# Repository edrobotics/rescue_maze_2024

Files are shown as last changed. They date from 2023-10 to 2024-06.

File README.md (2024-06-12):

# Rescue Maze 2024

Repository for ED Robotics' participation in the Robocup Junior Rescue Maze 2024 competition.

The contents of this repository were used in RoboCup Junior SM (Swedish Championships) 2024.

The code and CAD models are provided as-is, without any additional work done after the competition. The code (and hardware) did not work as expected, so keep that in mind.

## Performance

- RoboCupJunior Sweden 2024: Last place, 5 points :(

## Conclusions

Minimum Viable Product is a good idea that probably should have been prioritised more.

## Note:

This was our second year doing robotics. The code may contain trace amounts of spaghetti.

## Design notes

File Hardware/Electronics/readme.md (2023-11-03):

# Electronics
In this folder, all electronics-related things are stored. This is mostly schematics and PCBs.

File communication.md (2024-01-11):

# Communication standards for EDR RCJ2024
## Teensy to Pi
Communication method: I2C

Information from teensy to Pi:
- Motor data
  - Speed
  - Position - Position since last call to startDistanceMeasure
- ToF data
- IMU Data
- Colour sensor data
- Battery voltage

Information from Pi to teensy:
- Motor control values
  - Wanted speed
  - Acceleration limits?

### Concrete implementation
The two computers are synchronized. Communication (and some more things) happen like this:

<!-- Websequencediagrams code for the following image (could also use js-sequence-diagrams)
title Communication: Teensy-Pi
Pi->Teensy: Write control data
note right of Teensy: While waiting, run motor control loop
Pi->Teensy: Write control data end
note right of Teensy: Use the control data
Pi->Teensy: Check if data is ready
Teensy->Pi: Respond if ready or not (if it has\nbeen updated since last read)
Pi->Teensy: I want to read data
Teensy->Pi: Data
note right of Teensy: While sending data, read all other sensors\n(and perform misc. tasks)
Pi->Teensy: I have read all that I want
note right of Teensy: Set data ready flag to 0
note right of Teensy: Continue reading sensors if needed
note right of Teensy: Update the data read variable (byte array)
note right of Teensy: Set data ready flag to 1
note right of Teensy: Wait for new control data write (go back to top) -->

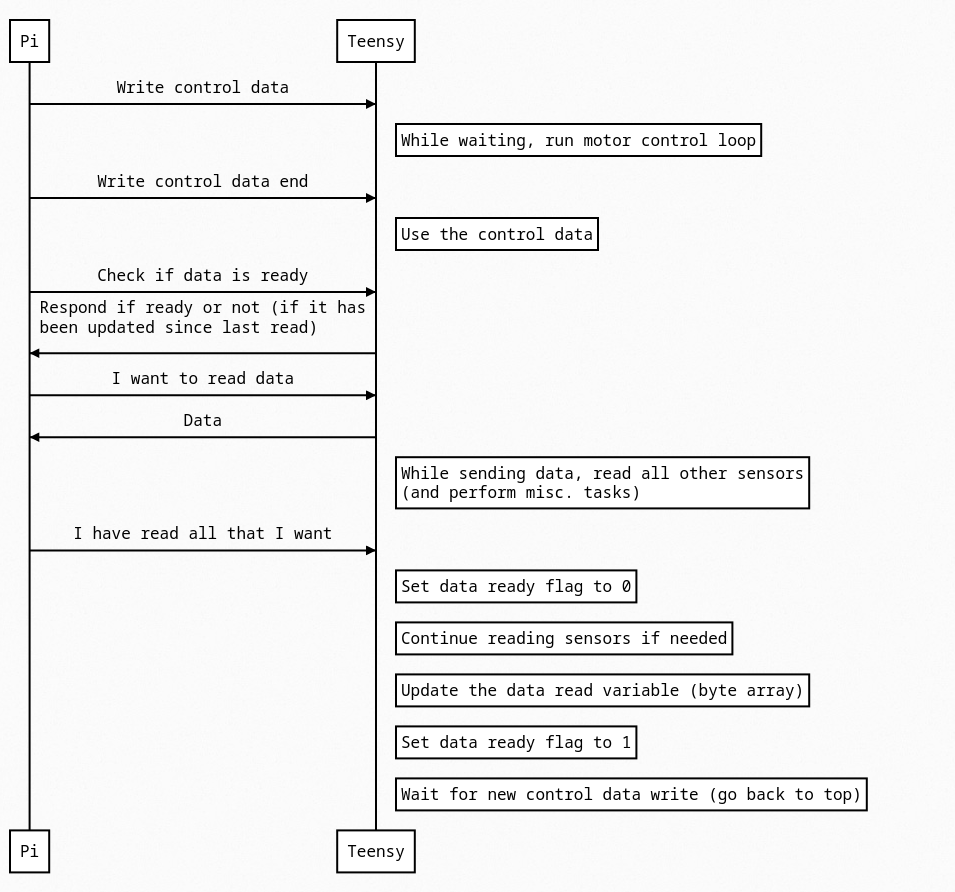
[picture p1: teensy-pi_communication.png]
Communication diagram


## Vision to Navigation
Communication method: Socket communication

Port: 4242  
Bidirectional: Yes (?)

Information that the protocol should be able to transmit:

- Victim type (including none)
    - Also includes potential victims
- Victim position
- Timestamp for captured image frame

If victim is direclty right/left, first send potential victim, with position and timestamp. Then navigation slows down or stops and updates the slowing/stopping status to the vision program. Then a normal victim type may be sent, the side, position and timestamp.

If victim is in front or out to the sides (for example in adjacent tile), send an unconfirmed victim type, side, position(?) (different from potition above) and timestamp. Then it is up to global navigation to decide wether to investigate or not. Then normal victim handling takes over. No confirmations are sent.

### Concrete implementation
Start char: '!'  
Delimiter: ','

Message types:
- Victim detection: 'v'
- Confirmation: 'c'

Victim detection message structure: !v,\<detection type>,\<victim type>,\<camera>,\<position>,\<timestamp>

- Detection type: 'p'/'c'
- Victim type: 'g'/'y'/'r'/'u'/'s'/'h'
- Camera: Integer staring from 0, incrementing by 1. Fusion program determines left/right
- Position:
    - \<x-coord>,\<y-coord>
    - Integer in mm from the camera center of FOV. Positive direction is normal math coordinate system (positive right-up)
- Timestamp: Unix millisecond timestamp

Confirmation message structure: !c

## Navigation threads
Communication method: Shared variables

Data that should be shared:
- Local robot pose
- Global robot pose
- Array/vector/queue of commands for local to execute
- Fusion -> (global) -> local: detection slowdown
- Fusion -> global -> local: kit drop interrupt
    - Read what to drop and where from other variable
- speed setting (slow, normal, turbo)
- Ground colour data from fusion
- Ramp data: direction, x-length, y-length, (length)
- Väggar
- Obstacles?
- Bump sensor

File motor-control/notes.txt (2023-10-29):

PID Library: https://github.com/br3ttb/Arduino-PID-Library
Motor PID Library: https://github.com/natnqweb/Motor_PID

Need to make it clear how it is done whether both edges are counted or just one, with CPR.

Need to check all types, especially float/double with the PID Library

Left to do:
Migrate to teensy?
Tune constants
Handle integral windup
Incorporate PWM "bump"?
Finish calibration routine:
    Make linear regression on the Arduino
    Store the regression function in EEPROM(or other)
Communication with raspberry

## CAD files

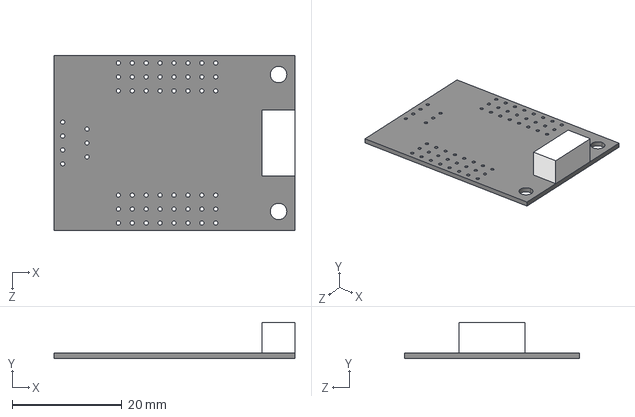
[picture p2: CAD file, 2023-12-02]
Hardware/CAD/Parts_library/dfrobot_io_expander.step
44.0 x 6.65 x 32.0 mm

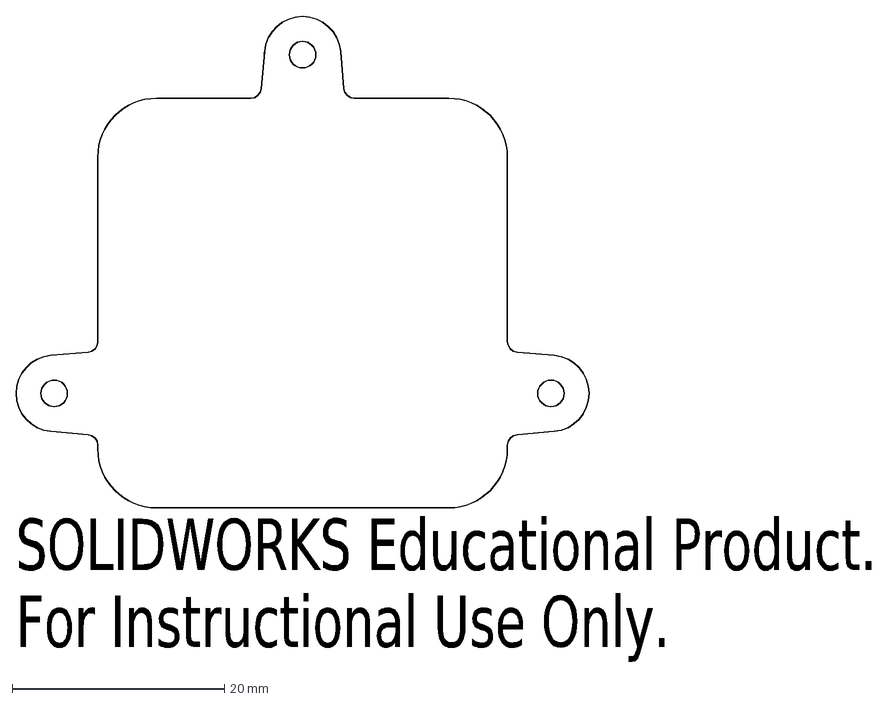
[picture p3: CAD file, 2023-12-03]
Hardware/Electronics/kicad_RCJ/3d-models/lidar_testing.DXF
SOLIDWORKS Educational Product.
For Instructional Use Only.

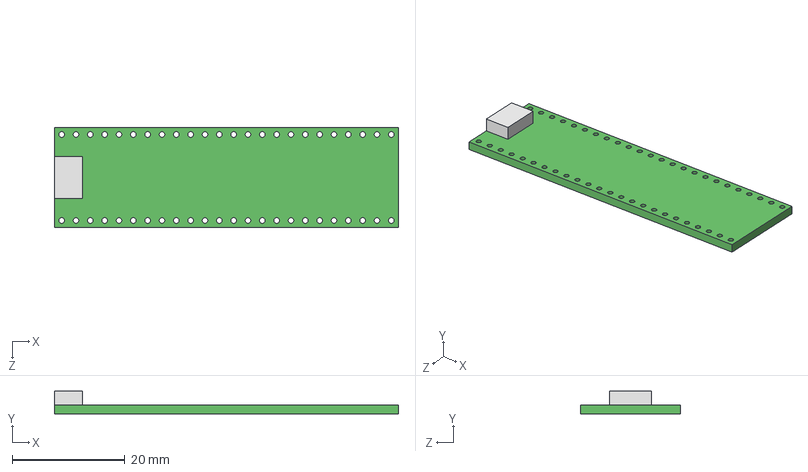
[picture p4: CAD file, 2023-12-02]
Hardware/CAD/Parts_library/teensy_4.1.step
61.0 x 4.07 x 17.8 mm

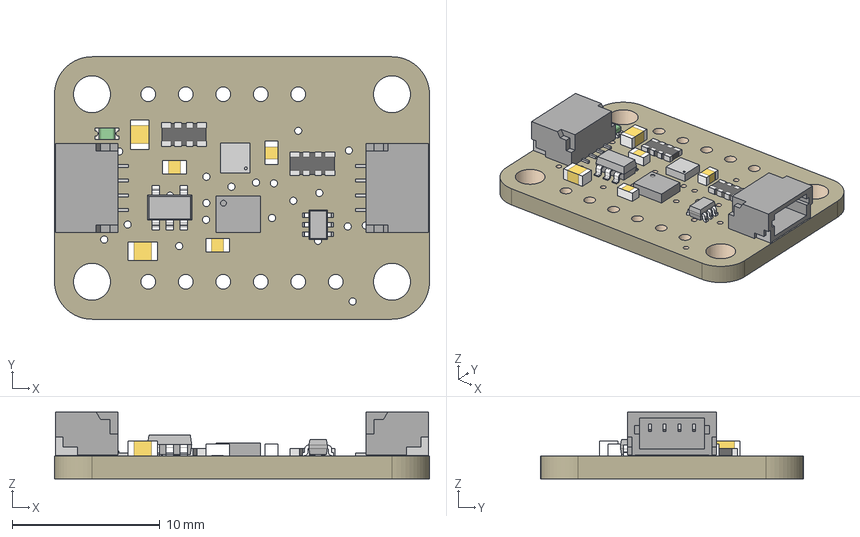
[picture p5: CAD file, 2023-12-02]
Hardware/Electronics/kicad_RCJ/3d-models/4517_LSM6DSOX-LIS3MDL.step
25.4 x 17.8 x 4.53 mm
Board
10uF x 2
AP2112K-3.3
1uF x 3
10K x 2
BSS138
STEMMA_I2C_QT x 2
GREEN
LIS3MDL
LSM6DSOX

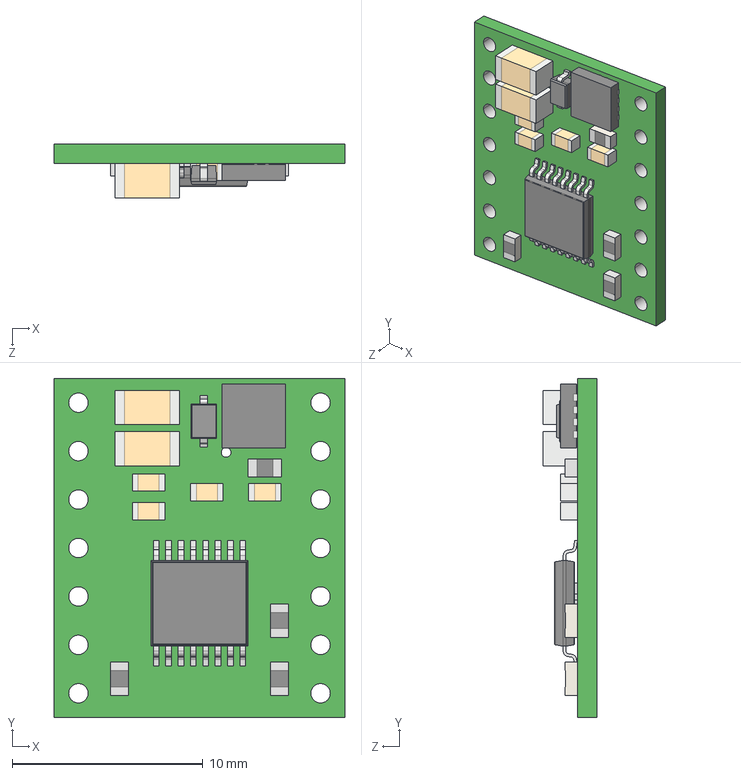
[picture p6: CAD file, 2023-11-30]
Hardware/Electronics/kicad_RCJ/3d-models/drv887x-single-brushed-dc-motor-driver-carrier.step
15.2 x 17.8 x 2.82 mm

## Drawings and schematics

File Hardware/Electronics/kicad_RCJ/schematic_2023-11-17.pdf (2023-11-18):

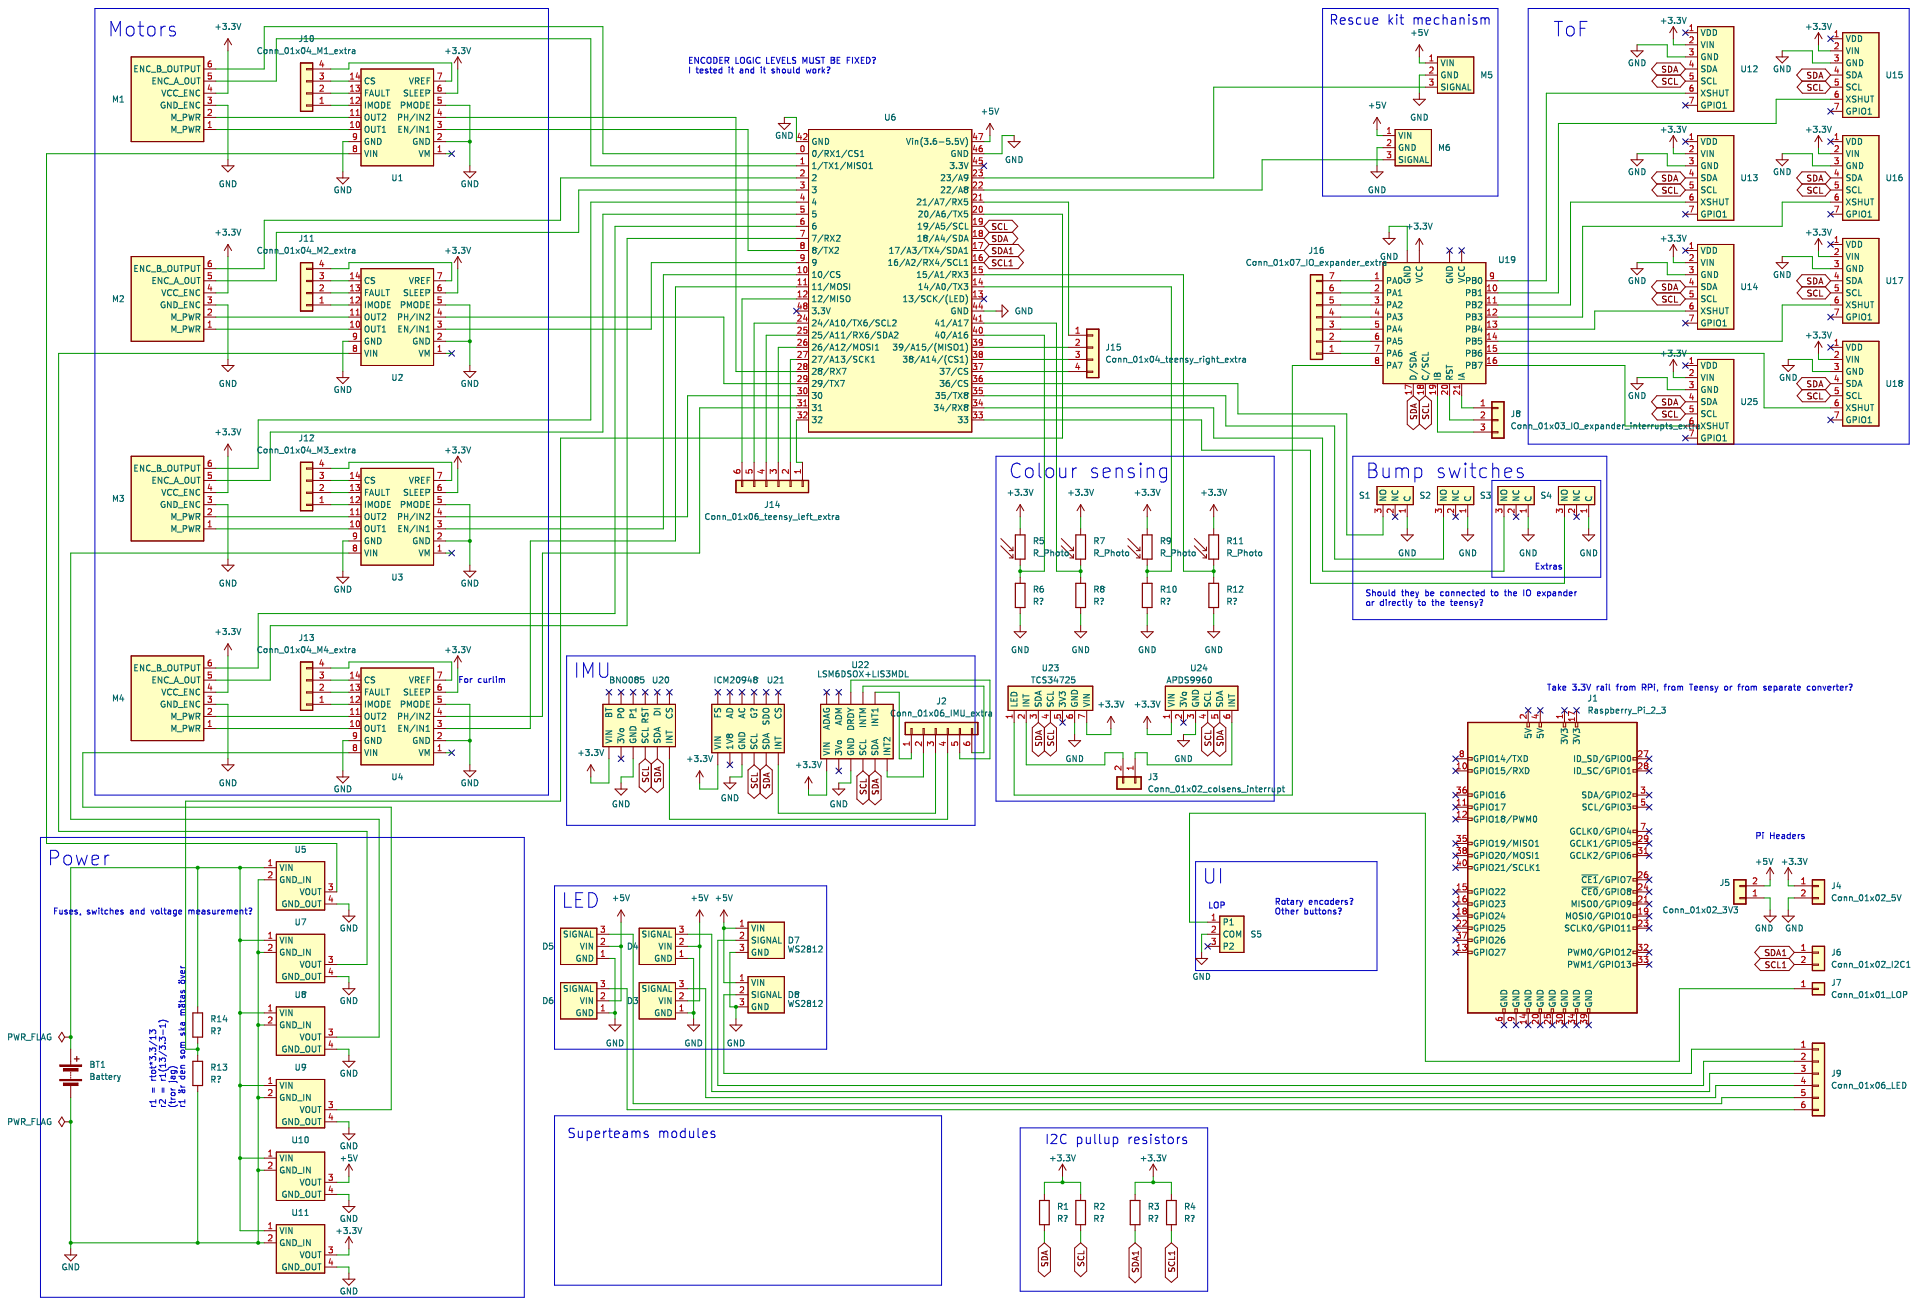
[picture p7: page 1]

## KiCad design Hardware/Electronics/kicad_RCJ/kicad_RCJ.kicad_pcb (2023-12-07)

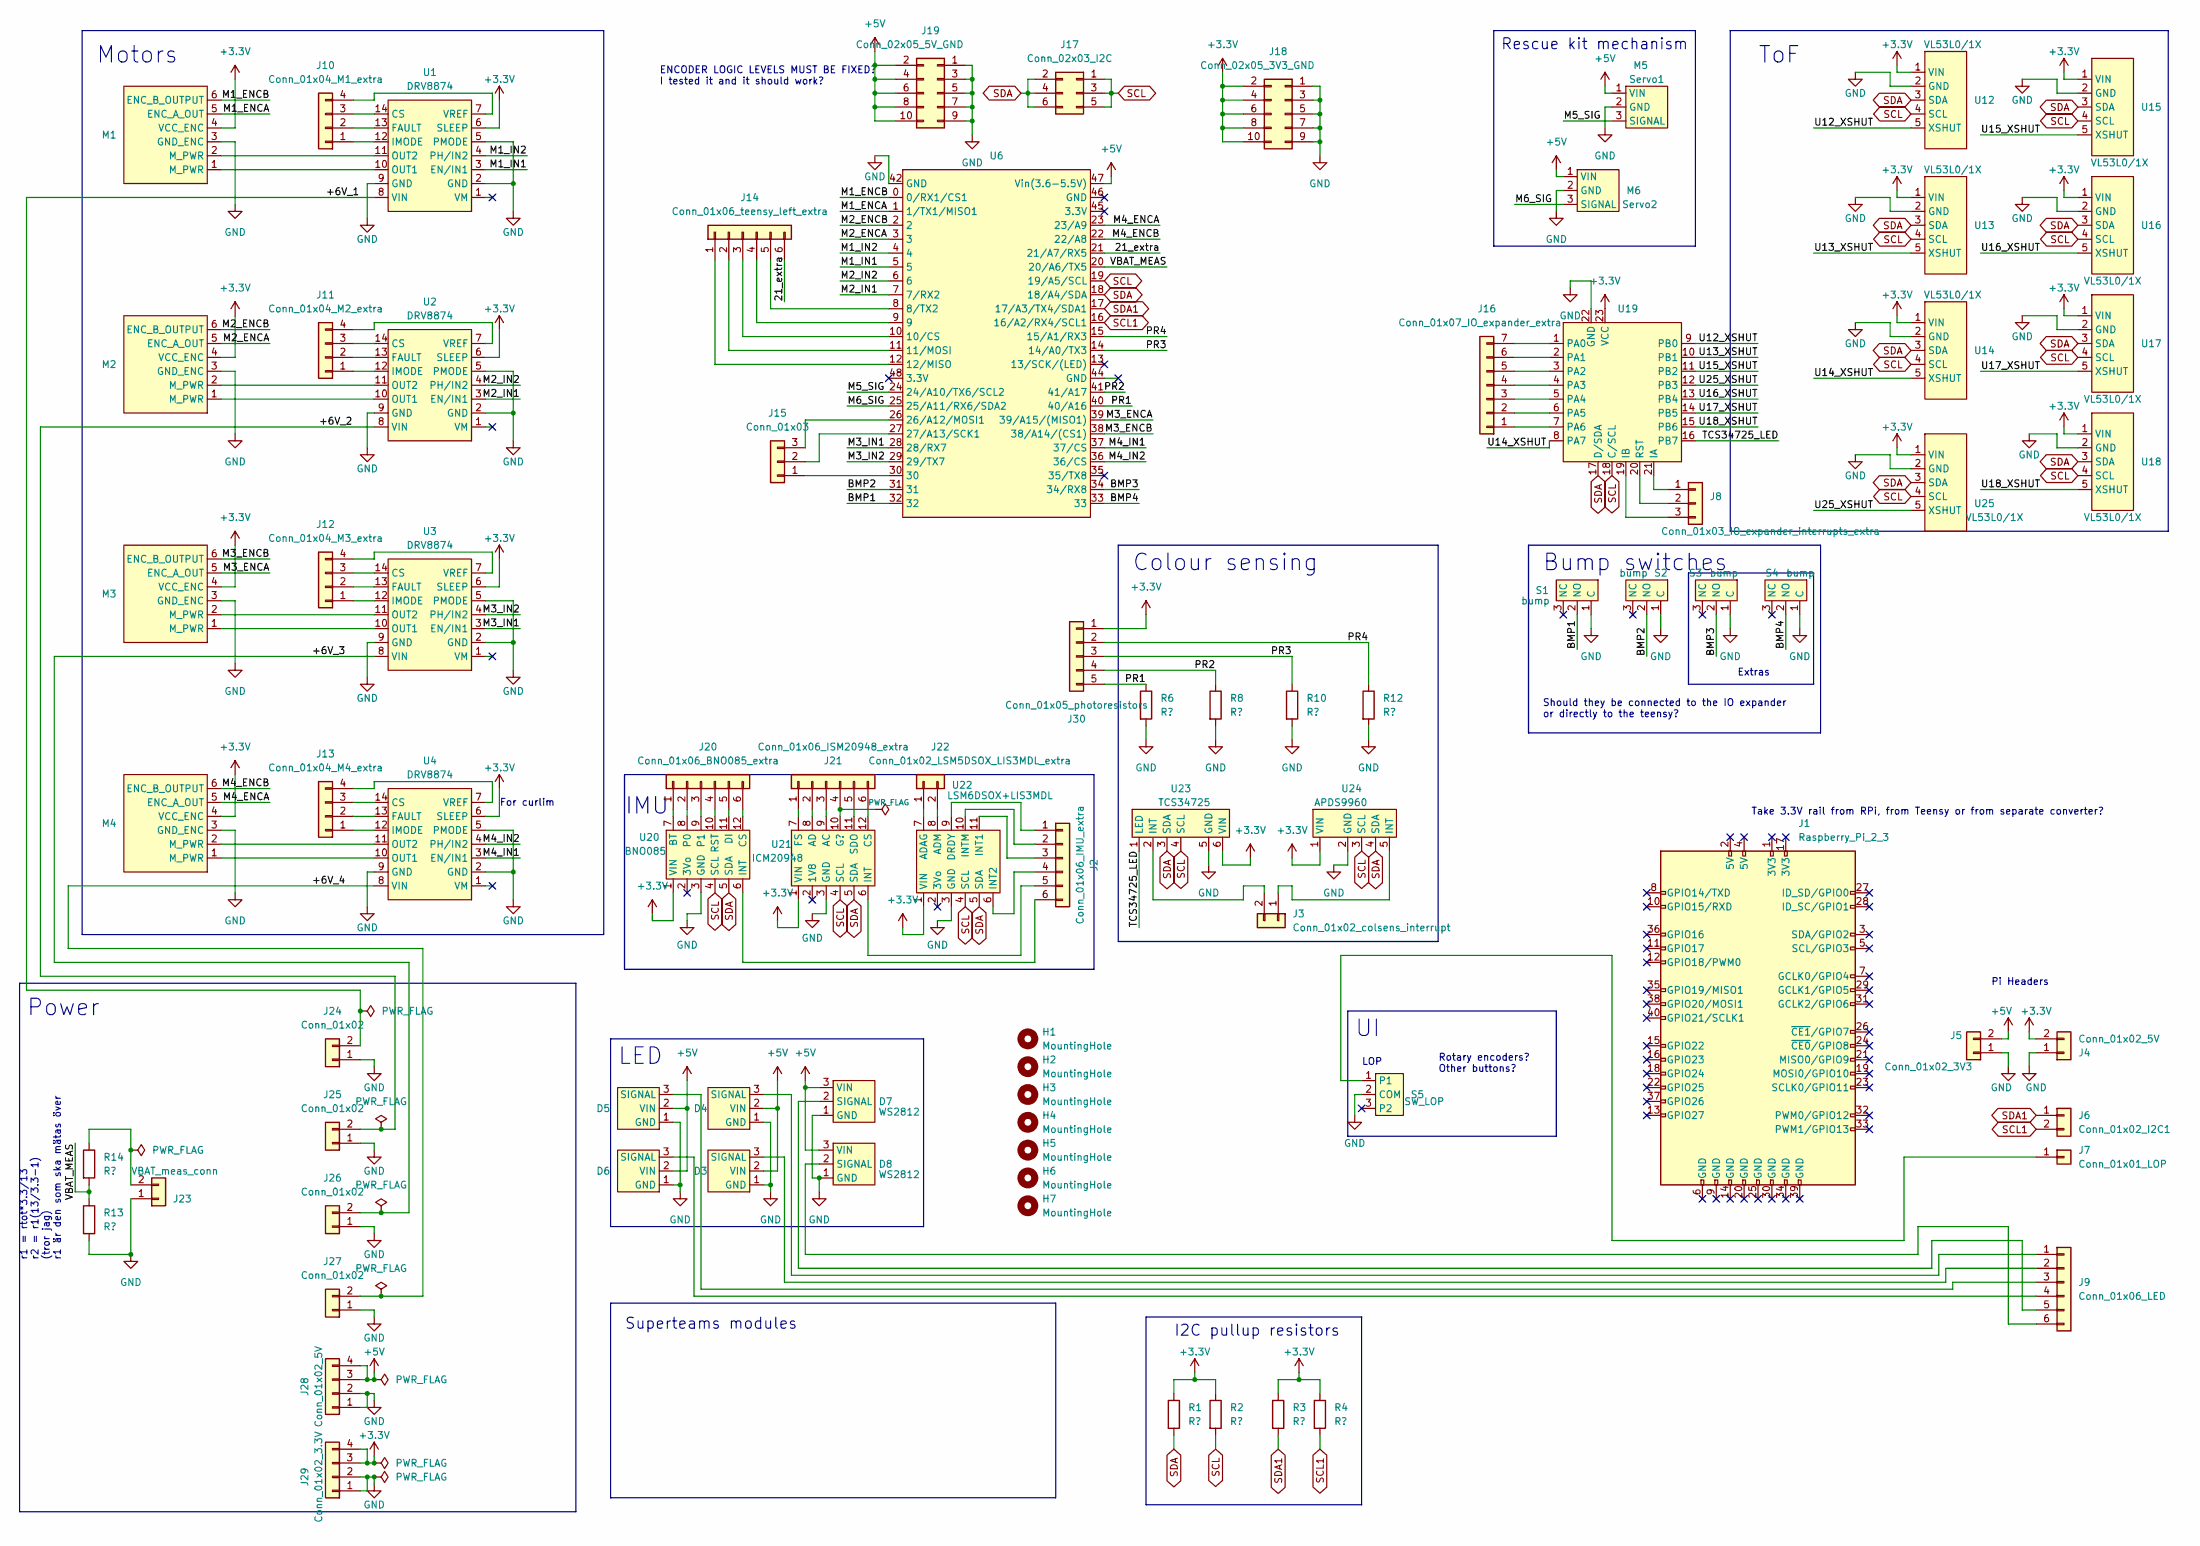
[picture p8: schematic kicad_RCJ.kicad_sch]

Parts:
D3, D4, D5, D6: PinSocket_1x03_P2.54mm_Vertical
D7, D8: WS2812; PinSocket_1x03_P2.54mm_Vertical
H1, H2, H3, H4, H5, H6, H7: MountingHole; MountingHole_3.2mm_M3
J1: Raspberry_Pi_2_3
J2: Conn_01x06_IMU_extra; PinSocket_1x06_P2.54mm_Vertical
J3: Conn_01x02_colsens_interrupt; PinSocket_1x02_P2.54mm_Vertical
J4: Conn_01x02_5V; JST_XH_B2B-XH-A_1x02_P2.50mm_Vertical
J5: Conn_01x02_3V3; JST_XH_B2B-XH-A_1x02_P2.50mm_Vertical
J6: Conn_01x02_I2C1; JST_XH_B2B-XH-A_1x02_P2.50mm_Vertical
J7: Conn_01x01_LOP; PinSocket_1x01_P2.54mm_Vertical
J8: Conn_01x03_IO_expander_interrupts_extra; PinSocket_1x03_P2.54mm_Vertical
J9: Conn_01x06_LED; PinSocket_1x06_P2.54mm_Vertical
J10: Conn_01x04_M1_extra; PinSocket_1x04_P2.54mm_Vertical
J11: Conn_01x04_M2_extra; PinSocket_1x04_P2.54mm_Vertical
J12: Conn_01x04_M3_extra; PinSocket_1x04_P2.54mm_Vertical
J13: Conn_01x04_M4_extra; PinSocket_1x04_P2.54mm_Vertical
J14: Conn_01x06_teensy_left_extra; PinSocket_1x06_P2.54mm_Vertical
J15: Conn_01x03; PinSocket_1x03_P2.54mm_Vertical
J16: Conn_01x07_IO_expander_extra; PinSocket_1x07_P2.54mm_Vertical
J17: Conn_02x03_I2C; PinSocket_2x03_P2.54mm_Vertical
J18: Conn_02x05_3V3_GND; PinSocket_2x05_P2.54mm_Vertical
J19: Conn_02x05_5V_GND; PinSocket_2x05_P2.54mm_Vertical
J20: Conn_01x06_BNO085_extra; PinSocket_1x06_P2.54mm_Vertical
J21: Conn_01x06_ISM20948_extra; PinSocket_1x06_P2.54mm_Vertical
J22: Conn_01x02_LSM5DSOX_LIS3MDL_extra; PinSocket_1x02_P2.54mm_Vertical
J23: VBAT_meas_conn; JST_XH_B2B-XH-A_1x02_P2.50mm_Vertical
J24, J25, J26, J27: Conn_01x02; JST_XH_B2B-XH-A_1x02_P2.50mm_Vertical
J28: Conn_01x02_5V; JST_XH_B4B-XH-A_1x04_P2.50mm_Vertical
J29: Conn_01x02_3.3V; JST_XH_B4B-XH-A_1x04_P2.50mm_Vertical
J30: Conn_01x05_photoresistors; JST_XH_B5B-XH-A_1x05_P2.50mm_Vertical
M1, M2, M3, M4: PinHeader_1x06_P2.54mm_Vertical
M5: Servo1; PinHeader_1x03_P2.54mm_Vertical
M6: Servo2; PinHeader_1x03_P2.54mm_Vertical
R1, R2, R3, R4, R6, R8, R10, R12, R13, R14: R?; R_Axial_DIN0207_L6.3mm_D2.5mm_P10.16mm_Horizontal
S1, S2, S3, S4: bump; JST_XH_B3B-XH-A_1x03_P2.50mm_Vertical
S5: SW_LOP; JST_XH_B3B-XH-A_1x03_P2.50mm_Vertical
U1, U2, U3, U4: DRV8874
U6: Teensy_41
U12, U13, U14, U15, U16, U17, U18, U25: VL53L0/1X; JST_XH_B5B-XH-A_1x05_P2.50mm_Vertical
U19: IO_Expander_nopower
U20: BNO085
U21: ICM20948; ICM2049
U22: LSM6DSOX+LIS3MDL
U23: TCS34725; JST_XH_B6B-XH-A_1x06_P2.50mm_Vertical
U24: APDS9960; JST_XH_B5B-XH-A_1x05_P2.50mm_Vertical

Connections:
+3.3V: J4.2, J18.2, J18.4, J18.6, J18.8, J18.10, J29.3, J29.4, J30.1, M1.4 (VCC_ENC), M2.4 (VCC_ENC), M3.4 (VCC_ENC), M4.4 (VCC_ENC), R1.1, R2.1, R3.1, R4.1, U1.6 (SLEEP), U2.6 (SLEEP), U3.6 (SLEEP), U4.6 (SLEEP), U12.1 (VIN), U13.1 (VIN), U14.1 (VIN), U15.1 (VIN), U16.1 (VIN), U17.1 (VIN), U18.1 (VIN), U19.23 (VCC), U20.1 (VIN), U21.1 (VIN), U22.1 (VIN), U23.6 (VIN), U24.1 (VIN), U25.1 (VIN)
+5V: D3.2 (VIN), D4.2 (VIN), D5.2 (VIN), D6.2 (VIN), D7.3 (VIN), D8.3 (VIN), J5.2, J19.2, J19.4, J19.6, J19.8, J19.10, J28.3, J28.4, M5.1 (VIN), M6.1 (VIN), U6.47 (Vin(3.6-5.5V))
/21_extra: J14.6, U6.21 (21/A7/RX5)
/+6V_1: J24.2, U1.8 (VIN)
/+6V_2: J25.2, U2.8 (VIN)
/+6V_3: J26.2, U3.8 (VIN)
/+6V_4: J27.2, U4.8 (VIN)
/BMP1: S1.2 (NO), U6.32
/BMP2: S2.2 (NO), U6.31
/BMP3: S3.2 (NO), U6.34 (34/RX8)
/BMP4: S4.2 (NO), U6.33
/M1_ENCA: M1.5 (ENC_A_OUT), U6.1 (1/TX1/MISO1)
/M1_ENCB: M1.6 (ENC_B_OUTPUT), U6.0 (0/RX1/CS1)
/M1_IN1: U1.3 (EN/IN1), U6.5
/M1_IN2: U1.4 (PH/IN2), U6.4
/M2_ENCA: M2.5 (ENC_A_OUT), U6.3
/M2_ENCB: M2.6 (ENC_B_OUTPUT), U6.2
/M2_IN1: U2.3 (EN/IN1), U6.7 (7/RX2)
/M2_IN2: U2.4 (PH/IN2), U6.6
/M3_ENCA: M3.5 (ENC_A_OUT), U6.39 (39/A15/(MISO1))
/M3_ENCB: M3.6 (ENC_B_OUTPUT), U6.38 (38/A14/(CS1))
/M3_IN1: U3.3 (EN/IN1), U6.28 (28/RX7)
/M3_IN2: U3.4 (PH/IN2), U6.29 (29/TX7)
/M4_ENCA: M4.5 (ENC_A_OUT), U6.23 (23/A9)
/M4_ENCB: M4.6 (ENC_B_OUTPUT), U6.22 (22/A8)
/M4_IN1: U4.3 (EN/IN1), U6.37 (37/CS)
/M4_IN2: U4.4 (PH/IN2), U6.36 (36/CS)
/M5_SIG: M5.3 (SIGNAL), U6.24 (24/A10/TX6/SCL2)
/M6_SIG: M6.3 (SIGNAL), U6.25 (25/A11/RX6/SDA2)
/PR1: J30.5, R6.1, U6.40 (40/A16)
/PR2: J30.4, R8.1, U6.41 (41/A17)
/PR3: J30.3, R10.1, U6.14 (14/A0/TX3)
/PR4: J30.2, R12.1, U6.15 (15/A1/RX3)
/TCS34725_LED: U19.16 (PB7), U23.1 (LED)
/U12_XSHUT: U12.5 (XSHUT), U19.9 (PB0)
/U13_XSHUT: U13.5 (XSHUT), U19.10 (PB1)
/U14_XSHUT: U14.5 (XSHUT), U19.8 (PA7)
/U15_XSHUT: U15.5 (XSHUT), U19.11 (PB2)
/U16_XSHUT: U16.5 (XSHUT), U19.13 (PB4)
/U17_XSHUT: U17.5 (XSHUT), U19.14 (PB5)
/U18_XSHUT: U18.5 (XSHUT), U19.15 (PB6)
/U25_XSHUT: U19.12 (PB3), U25.5 (XSHUT)
/VBAT_MEAS: R13.1, R14.2, U6.20 (20/A6/TX5)
GND: D3.1 (GND), D4.1 (GND), D5.1 (GND), D6.1 (GND), D7.1 (GND), D8.1 (GND), J4.1, J5.1, J18.1, J18.3, J18.5, J18.7, J18.9, J19.1, J19.3, J19.5, J19.7, J19.9, J23.1, J24.1, J25.1, J26.1, J27.1, J28.1, J28.2, J29.1, J29.2, M1.3 (GND_ENC), M2.3 (GND_ENC), M3.3 (GND_ENC), M4.3 (GND_ENC), M5.2 (GND), M6.2 (GND), R6.2, R8.2, R10.2, R12.2, R13.2, S1.1 (C), S2.1 (C), S3.1 (C), S4.1 (C), S5.2 (COM), U1.2 (GND), U1.5 (PMODE), U1.9 (GND), U2.2 (GND), U2.5 (PMODE), U2.9 (GND), U3.2 (GND), U3.5 (PMODE), U3.9 (GND), U4.2 (GND), U4.5 (PMODE), U4.9 (GND), U6.42 (GND), U12.2 (GND), U13.2 (GND), U14.2 (GND), U15.2 (GND), U16.2 (GND), U17.2 (GND), U18.2 (GND), U19.22 (GND), U20.3 (GND), U21.3 (GND), U22.3 (GND), U23.5 (GND), U24.2 (GND), U25.2 (GND)
unnamed: D3.3 (SIGNAL), J9.2
unnamed: D4.3 (SIGNAL), J9.1
unnamed: D5.3 (SIGNAL), J9.3
unnamed: D6.3 (SIGNAL), J9.4
unnamed: D7.2 (SIGNAL), J9.5
unnamed: D8.2 (SIGNAL), J9.6
unnamed: J2.1, U22.9 (DRDY)
unnamed: J2.2, U22.10 (INTM)
unnamed: J2.3, U22.11 (INT1)
unnamed: J2.4, U22.6 (INT2)
unnamed: J2.5, U21.6 (INT)
unnamed: J2.6, U20.6 (INT)
unnamed: J3.1, U24.5 (INT)
unnamed: J3.2, U23.2 (INT)
unnamed: J7.1, S5.1
unnamed: J8.1, U19.21 (IA)
unnamed: J8.2, U19.20 (RST)
unnamed: J8.3, U19.19 (IB)
unnamed: J10.1, U1.12 (IMODE)
unnamed: J10.2, U1.13 (FAULT)
unnamed: J10.3, U1.14 (CS)
unnamed: J10.4, U1.7 (VREF)
unnamed: J11.1, U2.12 (IMODE)
unnamed: J11.2, U2.13 (FAULT)
unnamed: J11.3, U2.14 (CS)
unnamed: J11.4, U2.7 (VREF)
unnamed: J12.1, U3.12 (IMODE)
unnamed: J12.2, U3.13 (FAULT)
unnamed: J12.3, U3.14 (CS)
unnamed: J12.4, U3.7 (VREF)
unnamed: J13.1, U4.12 (IMODE)
unnamed: J13.2, U4.13 (FAULT)
unnamed: J13.3, U4.14 (CS)
unnamed: J13.4, U4.7 (VREF)
unnamed: J14.1, U6.12 (12/MISO)
unnamed: J14.2, U6.11 (11/MOSI)
unnamed: J14.3, U6.10 (10/CS)
unnamed: J14.4, U6.9
unnamed: J14.5, U6.8 (8/TX2)
unnamed: J15.1, U6.30
unnamed: J15.2, U6.27 (27/A13/SCK1)
unnamed: J15.3, U6.26 (26/A12/MOSI1)
unnamed: J16.1, U19.7 (PA6)
unnamed: J16.2, U19.6 (PA5)
unnamed: J16.3, U19.5 (PA4)
unnamed: J16.4, U19.4 (PA3)
unnamed: J16.5, U19.3 (PA2)
unnamed: J16.6, U19.2 (PA1)
unnamed: J16.7, U19.1 (PA0)
unnamed: J20.1, U20.7 (BT)
unnamed: J20.2, U20.8 (P0)
unnamed: J20.3, U20.9 (P1)
unnamed: J20.4, U20.10 (RST)
unnamed: J20.5, U20.11 (DI)
unnamed: J20.6, U20.12 (CS)
unnamed: J21.1, U21.7 (FS)
unnamed: J21.2, U21.8 (AD)
unnamed: J21.3, U21.9 (AC)
unnamed: J21.4, U21.10 (G?)
unnamed: J21.5, U21.11 (SDO)
unnamed: J21.6, U21.12 (CS)
unnamed: J22.1, U22.7 (ADAG)
unnamed: J22.2, U22.8 (ADM)
unnamed: J23.2, R14.1
unnamed: M1.1 (M_PWR), U1.10 (OUT1)
unnamed: M1.2 (M_PWR), U1.11 (OUT2)
unnamed: M2.1 (M_PWR), U2.10 (OUT1)
unnamed: M2.2 (M_PWR), U2.11 (OUT2)
unnamed: M3.1 (M_PWR), U3.10 (OUT1)
unnamed: M3.2 (M_PWR), U3.11 (OUT2)
unnamed: M4.1 (M_PWR), U4.10 (OUT1)
unnamed: M4.2 (M_PWR), U4.11 (OUT2)
SCL: J17.1, J17.3, J17.5, R2.2, U6.19 (19/A5/SCL), U12.4 (SCL), U13.4 (SCL), U14.4 (SCL), U15.4 (SCL), U16.4 (SCL), U17.4 (SCL), U18.4 (SCL), U19.18 (C/SCL), U20.4 (SCL), U21.4 (SCL), U22.4 (SCL), U23.4 (SCL), U24.3 (SCL), U25.4 (SCL)
SCL1: J6.2, R4.2, U6.16 (16/A2/RX4/SCL1)
SDA: J17.2, J17.4, J17.6, R1.2, U6.18 (18/A4/SDA), U12.3 (SDA), U13.3 (SDA), U14.3 (SDA), U15.3 (SDA), U16.3 (SDA), U17.3 (SDA), U18.3 (SDA), U19.17 (D/SDA), U20.5 (SDA), U21.5 (SDA), U22.5 (SDA), U23.3 (SDA), U24.4 (SDA), U25.3 (SDA)
SDA1: J6.1, R3.2, U6.17 (17/A3/TX4/SDA1)

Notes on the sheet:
IMU
Motors
r1 = rtot*3.3/13 r2 = r1(13/3.3-1) (tror jag) r1 är den som ska mätas över
Take 3.3V rail from RPi, from Teensy or from separate converter?
ENCODER LOGIC LEVELS MUST BE FIXED? I tested it and it should work?
ToF
Extras
Power
LED
Superteams modules
Rotary encoders? Other buttons?
Colour sensing
Rescue kit mechanism
Should they be connected to the IO expander or directly to the teensy?
For curlim
Pi Headers
LOP
Bump switches
I2C pullup resistors

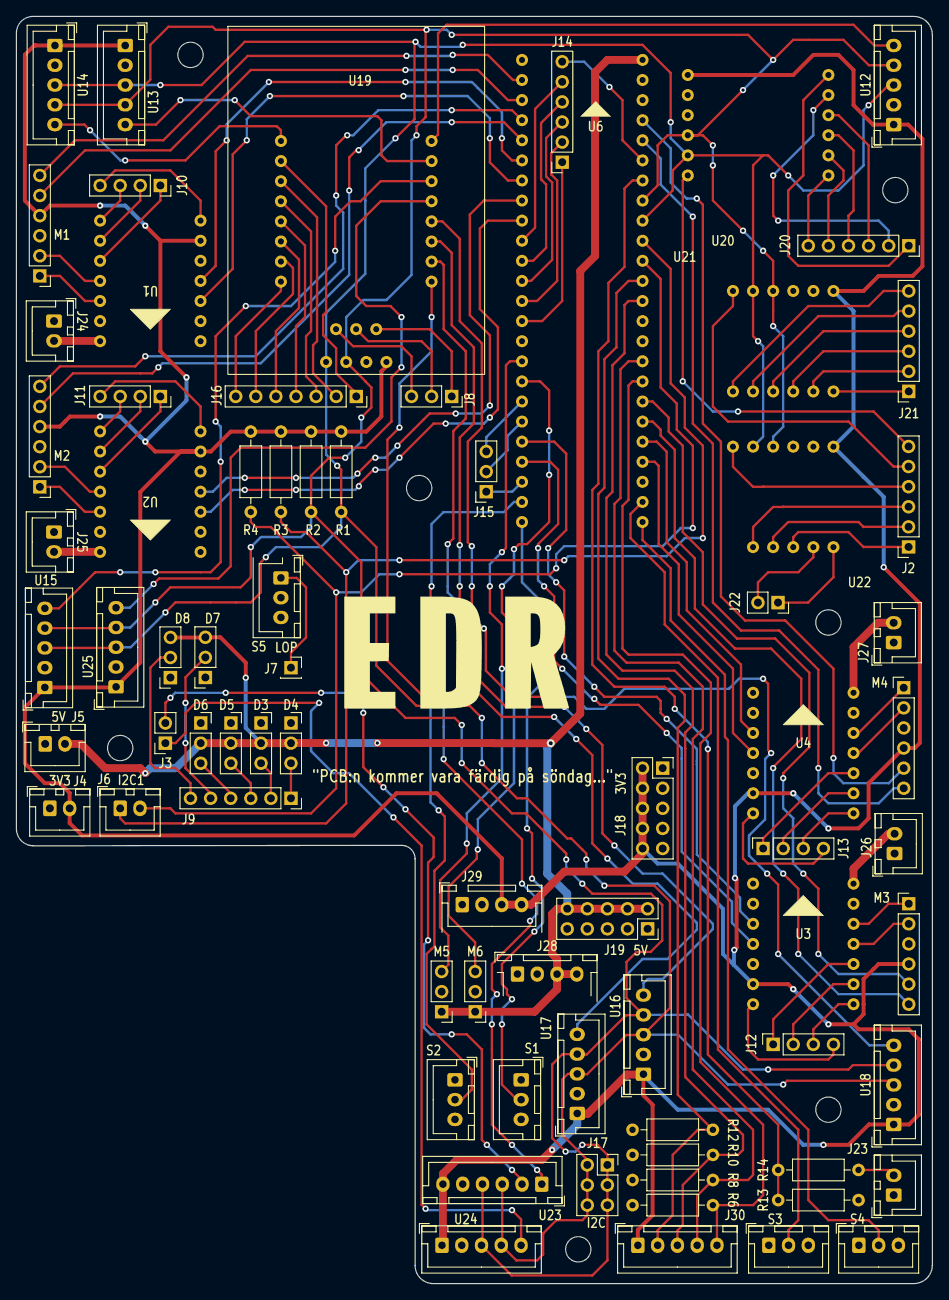
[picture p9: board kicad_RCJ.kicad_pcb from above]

Board: 2 copper layers, 115.8 x 160.2 mm, 82 parts (0 on the bottom side), 120 nets.

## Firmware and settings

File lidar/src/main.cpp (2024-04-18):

#include <opencv2/opencv.hpp>

#include <lidar/ldlidar_driver/ldlidar_driver_linux.h>

#include <iostream>
#include <chrono>
#include <math.h>

#include <lidar/lidar.h>

using namespace std;
using namespace ldlidar;
using namespace cv;

void displayImage(Mat& lineImg, LidarLineAnalyser& lAnalyser);


int main() //Expandera mer i riktningen åt senare och tidigare punkter? (om de är sorterade efter vinkel i point2d)
{           //Read/write intensity in txt
    Lidar lidar;

    while (true)
    {
        auto start = std::chrono::high_resolution_clock::now();

        lidar.getLidarPose();

        auto end = std::chrono::high_resolution_clock::now();
        std::cout << "Full analysis:" << std::chrono::duration_cast<std::chrono::microseconds>(end-start).count() << "µs" << std::endl;
    }

    // displayImage(showLines, lAnalyser);

    //**************************************   SAVING FILES    **************************************//

    string tNow = to_string(time(0));
    #ifdef CODE_SAVE_SCAN
    imwrite(SCAN_BASENAME + tNow + string(".png"), image);
    #endif
    #ifdef CODE_SAVE_SCANPLT
    imwrite(SCAN_BASENAME + tNow + string("_PLT.png"), showLines);
    #endif
    #ifdef CODE_SAVE_LATEST
    imwrite(SCAN_BASENAME + "latest_PLT.png", showLines);
    imwrite(SCAN_BASENAME + "latest.png", image);
    #endif

    #ifdef CODE_SAVE_TXT
    writeFile(points);
    #endif

    return 0;
}

void displayImage(Mat& lineImg, LidarLineAnalyser& lAnalyser)
{
    double orientation = lAnalyser.getOrientation();
    Point relativePosition = lAnalyser.getTilePosition();
    std::array<std::array<cv::Vec<bool, 4>, TILE_READ_AMOUNT>, TILE_READ_AMOUNT> relMap = lAnalyser.getMap().relativeMap;

    Mat relativeImg = imread(BASEIMGPATH);

    line(lineImg, Point(0, ORIGIN_Y), Point(IMG_SIZE[0], ORIGIN_Y), Scalar(200,200,200));
    line(lineImg, Point(ORIGIN_X, 0), Point(ORIGIN_X, IMG_SIZE[1]), Scalar(200,200,200));
    line(relativeImg, Point(0, ORIGIN_Y), Point(IMG_SIZE[0], ORIGIN_Y), Scalar(200,200,200));
    line(relativeImg, Point(ORIGIN_X, 0), Point(ORIGIN_X, IMG_SIZE[1]), Scalar(200,200,200));

    for (int i = 0; i < 2000; i += 300)
    {
        line(lineImg, transformPoint(Point(0, ORIGIN_Y + relativePosition.y - i), ORIGIN, -orientation)+ORIGIN, transformPoint(Point(IMG_SIZE[0], ORIGIN_Y + relativePosition.y - i), ORIGIN, -orientation)+ORIGIN, Scalar(200,100,200));
        line(lineImg, transformPoint(Point(ORIGIN_X + relativePosition.x - i, 0), ORIGIN, -orientation)+ORIGIN, transformPoint(Point(ORIGIN_X + relativePosition.x - i, IMG_SIZE[1]), ORIGIN, -orientation)+ORIGIN, Scalar(200,100,200));
        line(lineImg, transformPoint(Point(0, ORIGIN_Y + relativePosition.y + i), ORIGIN, -orientation)+ORIGIN, transformPoint(Point(IMG_SIZE[0], ORIGIN_Y + relativePosition.y + i), ORIGIN, -orientation)+ORIGIN, Scalar(200,100,200));
        line(lineImg, transformPoint(Point(ORIGIN_X + relativePosition.x + i, 0), ORIGIN, -orientation)+ORIGIN, transformPoint(Point(ORIGIN_X + relativePosition.x + i, IMG_SIZE[1]), ORIGIN, -orientation)+ORIGIN, Scalar(200,100,200));
        
        line(relativeImg, Point(0, ORIGIN_Y - 150 - i), Point(IMG_SIZE[0], ORIGIN_Y - 150 - i), Scalar(200,100,200));
        line(relativeImg, Point(ORIGIN_X - 150 - i, 0), Point(ORIGIN_X - 150 - i, IMG_SIZE[1]), Scalar(200,100,200));
        line(relativeImg, Point(0, ORIGIN_Y + 150 + i), Point(IMG_SIZE[0], ORIGIN_Y + 150 + i), Scalar(200,100,200));
        line(relativeImg, Point(ORIGIN_X + 150 + i, 0), Point(ORIGIN_X + 150 + i, IMG_SIZE[1]), Scalar(200,100,200));
    }

	for (size_t i = 0; i < TILE_READ_AMOUNT; i++)
	{
		for (size_t j = 0; j < TILE_READ_AMOUNT; j++)
		{
			if (relMap[j][i][0])
				line(relativeImg, Point(i*300 - 300*TILE_READ_AMOUNT/2, j*300 - 300*TILE_READ_AMOUNT/2)+ORIGIN, Point((i+1)*300 - 300*TILE_READ_AMOUNT/2, j*300 - 300*TILE_READ_AMOUNT/2)+ORIGIN, Scalar(255, 255, 255), 3);
			if (relMap[j][i][1])
				line(relativeImg, Point(i*300 - 300*TILE_READ_AMOUNT/2, j*300 - 300*TILE_READ_AMOUNT/2)+ORIGIN, Point(i*300 - 300*TILE_READ_AMOUNT/2, (j+1)*300 - 300*TILE_READ_AMOUNT/2)+ORIGIN, Scalar(255, 255, 255), 3);
			if (relMap[j][i][2])
				line(relativeImg, Point((i+1)*300 - 300*TILE_READ_AMOUNT/2, (j+1)*300 - 300*TILE_READ_AMOUNT/2)+ORIGIN, Point((i+1-1)*300 - 300*TILE_READ_AMOUNT/2, (j+1)*300 - 300*TILE_READ_AMOUNT/2)+ORIGIN, Scalar(255, 255, 255), 3);
			if (relMap[j][i][3])
				line(relativeImg, Point((i+1)*300 - 300*TILE_READ_AMOUNT/2, (j+1)*300 - 300*TILE_READ_AMOUNT/2)+ORIGIN, Point((i+1)*300 - 300*TILE_READ_AMOUNT/2, (j+1-1)*300 - 300*TILE_READ_AMOUNT/2)+ORIGIN, Scalar(255, 255, 255), 3);
		}
	}

    circle(lineImg, Point(ORIGIN_X, ORIGIN_Y), 5, Scalar(255, 120, 255), 3);
    circle(relativeImg, Point(ORIGIN_X, ORIGIN_Y) - relativePosition + Point(150, 150), 5, Scalar(255, 120, 255), 3);

    cv::Range showSize(1000, 4000);

    string winName = "Combined lines (in red), Hough detected lines (in green)";
    namedWindow(winName, WINDOW_NORMAL);
    imshow(winName, lineImg(showSize, showSize));
    resizeWindow(winName, Size(1000, 1000));

    string winName2 = "Relative img";
    namedWindow(winName2, WINDOW_NORMAL);
    imshow(winName2, relativeImg(showSize, showSize));
    resizeWindow(winName2, Size(1000, 1000));
    waitKey(0);
}

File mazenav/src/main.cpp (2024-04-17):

#include <iostream>
#include <thread>
#include <fusion/fusion.h>
#include <globalNav/globalNav.h>
#include <localNav/localNav.h>

#include "communicator/communicator.h"
#include "fusion/PiAbstractor.h"

// Object used for communication
communication::Communicator comm {};

PiAbstractor piAbs {};


int main()
{
    piAbs.init();
    
    std::thread fusionT = std::thread(fusion::main, &comm, &piAbs);
    std::thread globNavT = std::thread(globalNav::main, &comm);
    std::thread locNavT = std::thread(localNav::main, &comm, &piAbs);

    fusionT.join();
    globNavT.join();
    locNavT.join();

    return 0;
}

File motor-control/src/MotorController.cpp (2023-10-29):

#include "MotorController.h"


MotorController::MotorController(int enA, int enB, int pwmPin, int dirPin, double encRatio, int cpr) : encoder(enA, enB)
{
    this->pwmPin = pwmPin;
    this->dirPin = dirPin;
    this->encOutputRatio = encRatio;
    this->cpr = cpr;
}

bool MotorController::init()
{

    // PID Setup
    pid.SetMode(QuickPID::Control::automatic);
    pid.SetOutputLimits(-255, 255); // Limits for setPwm(), positive and negative
    #warning untuned sample time
    pid.SetSampleTimeUs(pidSampleTimeUs);
    #warning PID setup not done!(?)

    pinMode(dirPin, OUTPUT);
    pinMode(pwmPin, OUTPUT);

    // Nothing went wrong, so we return true (otherwise we returned false earlier)
    return true;
}

void MotorController::setSpeed(double speed)
{
    // outputSpeed = speed; // Should not be updated here? Not needed?
    motorSpeed = speed*encOutputRatio;
}

void MotorController::setPWM(int pwmSpeed)
{
    if (pwmSpeed>255)
    {
        pwmSpeed = 255;
    }
    else if (pwmSpeed<-255)
    {
        pwmSpeed = -255;
    }

    #warning unsure if high or low means forwards or backwards
    if (pwmSpeed>0)
    {
        digitalWrite(dirPin, (!isReversed) ? LOW : HIGH);
    }
    else
    {
        digitalWrite(dirPin, (isReversed) ? LOW : HIGH);
    }
    analogWrite(pwmPin, abs(pwmSpeed));

    curPWM = pwmSpeed;
}

double MotorController::rpmToPwm(double rpmSpeed)
{
    // return rpmSpeed/encOutputRatio;
    return rpmSpeed/33.4154675813246;
}

bool MotorController::update()
{
    update(true);
}

bool MotorController::update(bool usePIDCorr)
{
    long updateTime = micros();
    static long lastUpdateTime = 0;
    static long lastEncoderPos = 0;
    
    // Check that enough time has passed, so that we do not calculate stuff unnecessarily
    if (updateTime-lastUpdateTime < pidSampleTimeUs+300)
    {
        return false;
    }

    long read = encoder.read();
    encoderPos = (isReversed) ? -read : read;

    // Calculate speeds
    #warning possible overflows and truncations ahead. Fixed?
    if (updateTime==lastUpdateTime) return; // Would result in division by 0
    curMotorSpeed = double(encoderPos-lastEncoderPos)/double(cpr*(updateTime-lastUpdateTime)) * double(MICROS_PER_MINUTE);
    // If the value is this large, something is wrong. Should fix problems with very negative numbers.
    if (abs(curMotorSpeed)>15000)
    {
        #warning dirty fix for the negative values? Yes, it is dirty and it blocks the PID for long periods when the value is negative
        return false;
    }

    // PID Loop calculation
    // Updates speedCorrection
    // Returns if not enough time has passed
    if (!pid.Compute())
    {
        Serial.println("----------------------ABORTED----------------------------");
        return false;
    }

    if (motorSpeed==0)
    {
        #warning crude solution for integral term problem that will not work later
        pid.Reset(); // Reset the controller to prevent integral windup.
    }
    
    // Speed correction by PWM
    if (usePIDCorr==true)
    {
        setPWM(rpmToPwm(motorSpeed)+speedCorrection);
    }

    // Serial.print("encoderPos:");Serial.print(encoderPos);Serial.print(",");
    // Serial.print(";Serial.print(encoderPos);Serial.print(",");
    // Serial.print("lastEncoderPolastEncoderPos:");Serial.print(lastEncoderPos);Serial.print(",");
    // Serial.print("deltaEncoderPos:");Serial.print(encoderPos-lastEncoderPos);Serial.print(",");
    // Serial.print("updateTime:");Serial.print(updateTime);Serial.print(",");
    // Serial.print("lastUpdateTime:");Serial.print(lastUpdateTime);Serial.print(",");
    // Serial.print("deltaTime:");Serial.print(updateTime-lastUpdateTime);Serial.print(",");
    // Serial.print("curMotorSpeed:");Serial.print(curMotorSpeed);Serial.print(",");
    // Serial.println("");

    // Set variables for next time
    lastEncoderPos = encoderPos;
    lastUpdateTime = updateTime;
    return true;
}

void MotorController::startDistanceMeasure()
{
    tickStartDistance = encoderPos;
}


double MotorController::getDistance()
{
    return (encoderPos-tickStartDistance)/(cpr*encOutputRatio);
}

double MotorController::getOutputSpeed()
{
    return curMotorSpeed/encOutputRatio;
}

void MotorController::printValues()
{
    Serial.print("motorSpeed:");Serial.print(motorSpeed);Serial.print(",");
    Serial.print("curMotorSpeed:");Serial.print(curMotorSpeed);Serial.print(",");
    // Serial.print("curPWM:");Serial.print(curPWM);Serial.print(",");
    Serial.print("speedCorrection:");Serial.print(speedCorrection);Serial.print(",");
    // Serial.print("error:");Serial.print(motorSpeed-curMotorSpeed);Serial.print(",");
    Serial.print("outputSpeed:");Serial.print(getOutputSpeed());Serial.print(",");
    Serial.print("encoderPos:");Serial.print(encoderPos);Serial.print(",");
    Serial.println("");
}

void MotorController::printMotorSpeed()
{
    Serial.println(curMotorSpeed);
}
















void MotorController::pwmRPMCalibration()
{
    // Input parameters
    int startPWM = 40;
    int endPWM = 255;
    int pwmStep = 20;
    int toTest = 2*((endPWM-startPWM)/pwmStep + 2)+1; // Truncation on purpose
    int middle = toTest/2; // Truncation on purpose
    
    double rpms[toTest];
    int pwms[toTest] {};

    // Set pwms to test
    pwms[middle] = 0;
    for (int i=startPWM;i<=endPWM;i+=pwmStep)
    {
        static int num = middle+1;
        pwms[num] = i;
        pwms[2*middle - num] = -i;

        ++num;
    }
    pwms[toTest-1] = endPWM;
    pwms[0] = -endPWM;

    // Run the motors and calculate the rpms
    for (int i=0;i<toTest;++i)
    {
        rpms[i] = calibrateSinglePWM_RPM(pwms[i]);
        delay(1000);
    }

    // Print the data to serial (to be replaced with calculation later)
    Serial.println("---------------Calibration data for motor---------------");
    for (int i=0;i<toTest;++i)
    {
        printCsvVars(pwms[i], rpms[i]);
    }
    Serial.println("---------------END---------------");
}

double MotorController::calibrateSinglePWM_RPM(int pwmToCal)
{
    if (pwmToCal<0)
    {
        setPWM(-200);
    }
    else if (pwmToCal==0)
    {
        setPWM(0);
    }
    else
    {
        setPWM(200);
    }
    delay(42);
    setPWM(pwmToCal);
    delay(169);
    double motorSpeedSum = 0;
    for (int i=0;i<calibrationIterations;++i)
    {
        while(!update(false))
        {
            delay(1);
        }
        motorSpeedSum+=curMotorSpeed;
    }
    setPWM(0);
    return motorSpeedSum/double(calibrationIterations);

}

void MotorController::printCsvVars(int PWM, double RPM)
{
    Serial.print(PWM);Serial.print(",");Serial.print(RPM);Serial.println("");
}

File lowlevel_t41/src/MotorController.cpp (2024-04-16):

#include "MotorController.h"


MotorController::MotorController(int enA, int enB, int pwmPin, int dirPin, double encRatio, int cpr) : encoder(enA, enB)
{
    this->pwmPin = pwmPin;
    this->dirPin = dirPin;
    this->encOutputRatio = encRatio;
    this->cpr = cpr;
}

bool MotorController::init()
{

    // PID Setup
    pid.SetMode(QuickPID::Control::automatic);
    pid.SetControllerDirection(QuickPID::Action::direct);
    pid.SetOutputLimits(-255, 255); // Limits for setPwm(), positive and negative. Should be narrower?
    pid.SetSampleTimeUs(pidSampleTimeUs);

    pinMode(dirPin, OUTPUT);
    pinMode(pwmPin, OUTPUT);
    analogWriteFrequency(pwmPin, 80000); // Sets the frequency higher to reduce noise and make more like real analogue voltage?

    // Nothing went wrong, so we return true (otherwise we returned false earlier)
    return true;
}

void MotorController::setSpeed(double speed)
{
    motorSpeed = speed*encOutputRatio;
}

void MotorController::setPWM(int pwmSpeed)
{
    if (pwmSpeed>255)
    {
        pwmSpeed = 255;
    }
    else if (pwmSpeed<-255)
    {
        pwmSpeed = -255;
    }

    if (pwmSpeed>0)
    {
        digitalWrite(dirPin, (!isReversed) ? LOW : HIGH);
    }
    else
    {
        digitalWrite(dirPin, (isReversed) ? LOW : HIGH);
    }
    analogWrite(pwmPin, abs(pwmSpeed));

    curPWM = pwmSpeed;
}

bool MotorController::update()
{
    return update(true);
}

bool MotorController::update(bool usePIDCorr)
{
    unsigned long updateTime = micros();
    
    // Check that enough time has passed, so that we do not calculate stuff unnecessarily
    if (updateTime-lastUpdateTime < pidSampleTimeUs+300)
    {
        return false;
    }

    long read = encoder.read();
    encoderPos = (isReversed) ? -read : read;

    // Calculate speeds
    if (updateTime==lastUpdateTime) return false; // Would result in division by 0
    curMotorSpeed = double(encoderPos-lastEncoderPos)/double(cpr*(updateTime-lastUpdateTime)) * double(MICROS_PER_MINUTE);
    // Check for unreasonable values?

    // PID Loop calculation
    // Updates speedCorrection
    // Returns if not enough time has passed
    if (!pid.Compute())
    {
        Serial.println("----------------------ABORTED----------------------------");
        return false;
    }


    // Old way of computation
    // float newPWMVal = curPWM + speedCorrection;

    // New way of computation
    float newPWMVal = rpmToPwm(motorSpeed) + speedCorrection;

    if (abs(motorSpeed)<10 && abs(curMotorSpeed)<1000 && abs(newPWMVal) < 30)
    {
        newPWMVal = 0;
    }

    // Protection against stalling and getting stuck (motors cannot be driven above 252 in duty cycle)
    if (newPWMVal>250)
    {
        newPWMVal = 250;
    }
    else if (newPWMVal<-250)
    {
        newPWMVal = -250;
    }
    
    // Speed correction by PWM
    if (usePIDCorr==true)
    {
        setPWM(newPWMVal);
    }

    // printValues();

    // Set variables for next time
    lastEncoderPos = encoderPos;
    lastUpdateTime = updateTime;
    return true;
}

void MotorController::startDistanceMeasure()
{
    tickStartDistance = encoderPos;
}


int16_t MotorController::getDistanceDiff()
{
    int16_t retVal {double(encoderPos-tickStartDistance)/double(cpr*encOutputRatio)*WHEEL_CIRCUMFERENCE};
    startDistanceMeasure();
    return retVal;
}

double MotorController::getOutputSpeed()
{
    return curMotorSpeed/encOutputRatio;
}

void MotorController::printValues()
{
    Serial.print("motorSpeed:");Serial.print(motorSpeed);Serial.print(",");
    Serial.print("curMotorSpeed:");Serial.print(curMotorSpeed);Serial.print(",");
    Serial.print("curPWM:");Serial.print(curPWM);Serial.print(",");
    Serial.print("speedCorrection:");Serial.print(speedCorrection);Serial.print(",");
    // Serial.print("error:");Serial.print(motorSpeed-curMotorSpeed);Serial.print(",");
    Serial.print("outputSpeed:");Serial.print(getOutputSpeed());Serial.print(",");
    // Serial.print("encoderPos:");Serial.print(encoderPos);Serial.print(",");
    Serial.println("");
}


void MotorController::pwmRPMCalibration()
{
    LinearRegression reg {};

    for (int i=0;i<PWM_TEST_NUM;++i)
    {
        // Set the speed
        setPWM(PWM_TEST_POINTS[i]);
        // Wait until we reach speed
        delay(1000);
        // Make sure we read correct speed
        for (int k=0;k<10;++k)
        {
            update(false);
            delay(100);
        }

        // Read the speed and pwm and add to regression
        reg.learn(curMotorSpeed, curPWM);
    }

    // Update the coefficients
    reg.parameters(regCoeff);

    // Show the values.
    Serial.print("Parameters for motor calibration: y=kx+m, where k=");Serial.print(kVal, 10);Serial.print(", m=");Serial.print(mVal, 10);Serial.print(". To make the values take permanent effect, put these values in the code and reflash the code.");Serial.println();
    setPWM(0);
}

double MotorController::rpmToPwm(double rpm)
{
    return kVal*rpm+mVal;
}

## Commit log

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2023-10-29 fixed motor controller direction and added debugging
2023-10-29 added some self-calibration for pwm to rpm curves and also did some other stuff
2023-10-29 fixed encoder position overflow bug and rpm to pwm translation, so the essentials work.
    [MotorController.cpp, main.cpp]
2023-11-03 added initial electronics design (already quite a lot done)
    [kicad_RCJ.kicad_pcb, kicad_RCJ.kicad_sch]
2023-11-03 added I2C pullup resistors and I2C between teensy and pi
    [kicad_RCJ.kicad_sch]
2023-11-03 added bump switches and colour sensing and did general cleanup and organization
    [kicad_RCJ.kicad_sch]
2023-11-03 added voltage divider and measurement for battery voltage
    [kicad_RCJ.kicad_sch]
2023-11-05 misc. electronics work
    [kicad_RCJ.kicad_sch]
2023-11-16 schematic finished?
    [kicad_RCJ.kicad_sch]
2023-11-17 assigned some footprints
    [kicad_RCJ.kicad_sch]
2023-11-18 clarified schematic and added some headers
    [kicad_RCJ.kicad_sch]
2023-11-20 added some footprints and began laying out pcb
    [kicad_RCJ.kicad_pcb, kicad_RCJ.kicad_sch]
2023-11-21 added some footprints and did some PCB layout work
    [kicad_RCJ.kicad_pcb, kicad_RCJ.kicad_sch]
2023-11-22 worked on PCB layout, made footprints etc.
    [kicad_RCJ.kicad_pcb, kicad_RCJ.kicad_sch]
2023-11-23 updated PCB layout
    [kicad_RCJ.kicad_pcb]
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2023-11-23 refined PCB layout and resolved some footprint issues
    [kicad_RCJ.kicad_pcb, kicad_RCJ.kicad_sch]
2023-11-30 added size constraints to PCB outline and changed layout accordingly
    [drv887x-single-brushed-dc-motor-driver-carrier.step, kicad_RCJ.kicad_pcb]
2023-12-01 added power delivery to PCB
    [kicad_RCJ.kicad_pcb, kicad_RCJ.kicad_sch]
2023-12-01 added courtyards to most custom footprints
    [kicad_RCJ.kicad_pcb]
2023-12-01 fixed some connector pin number issues (TOF and colour sensors)
    [kicad_RCJ.kicad_pcb, kicad_RCJ.kicad_sch]
2023-12-01 updated PCB STEP for test in CAD
    [kicad_RCJ.kicad_pcb]
2023-12-02 added teensy step file
    [teensy_4.1.step]
2023-12-02 added some 3d-mmodels to footprints in PCB
    [4517_LSM6DSOX-LIS3MDL.step, ICM20948_LSM6DSOX_copy.step, kicad_RCJ.kicad_pcb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]
2023-12-02 fixed teensy 4.1 step PCB colour
    [teensy_4.1.step]
2023-12-02 added 3d model for IO expander (something slightly off, keep in mind)
    [dfrobot_io_expander.step, kicad_RCJ.kicad_pcb]
2023-12-03 enlarged PCB outline and rearranged
    [kicad_RCJ.kicad_pcb, kicad_RCJ.kicad_sch, lidar_testing.DXF]
2023-12-03 increased component spacing and fixed custom footprints
    [kicad_RCJ.kicad_pcb, kicad_RCJ.kicad_sch]
2023-12-03 enlarged resistor footprint
    [kicad_RCJ.kicad_pcb, kicad_RCJ.kicad_sch]
2023-12-04 did a lot of wiring
    [kicad_RCJ.kicad_pcb]
2023-12-06 continued routing of outer sections and rearranged parts of schematic for better routing
    [kicad_RCJ.kicad_pcb, kicad_RCJ.kicad_sch]
2023-12-07 finished essential routing (some extras left)
    [kicad_RCJ.kicad_pcb, kicad_RCJ.kicad_sch]
2023-12-07 PCB finished?
    [kicad_RCJ.kicad_pcb, kicad_RCJ.kicad_sch]
2023-12-07 PCB finished and manufacturing files produced
    [kicad_RCJ-B_Cu.gbl, kicad_RCJ-B_Mask.gbs, kicad_RCJ-B_Paste.gbp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]
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2023-12-21 added environment setting to build script and did misc. fixes
    [fusion.cpp, main.cpp]
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2023-12-29 fixed stall issue with motors
    [MotorController.cpp, main.cpp]
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2023-12-29 added some i2c and motor control code for teensy
2023-12-30 got I2C test between teensy and RPi working
2023-12-31 Fixed line merging, more comments
    [main.cpp]
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2024-01-02 spaghetti monster (I2C code) now works in basic tests
2024-01-05 updated IMU code (float to int) and restructured shared libraries
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2024-01-11 added test sensor. Should be ready for simple test
2024-01-12 added IMU sensor. Should be working alright now
2024-01-13 added other basic sensor files and classes (just skeleton, nowhere near done)
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2024-01-20 fixed compilation issue by passing pointer to communication object
    [main.cpp]
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2024-01-28 fixed transforms (?)(kind of) and some pedantic errors
    [MotorControllers.cpp, main.cpp]
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2024-01-30 hopefully fixed motor control bug (untested) (still need control system)
    [MotorControllers.cpp, Sensors.cpp]
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2024-02-18 Fixed inevitble bugs, should be the same as before file split now
    [main.cpp]
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2024-02-28 Add VisionCommunicator class for socket communication with vision
2024-02-29 added PID controller, added PID to kinematicdriver, misc. work on pathplanner/-follower. NO IDEA IF WORKING (PROBABLY NOT)
2024-03-01 Fixed lidar bugs
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2024-03-09 Vision communication should be mostly done, but might need to transform XY from camera to robot
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2024-04-09 fixed segfault (address boundary error) and other misc. possibly related things
    [Imu.cpp, MotorControllers.cpp, fusion.cpp]
2024-04-09 fixed some PoseEstimator problems. Now transX, tranxY and rotZ kind of work in some circumstances
    [Imu.cpp, fusion.cpp, main.cpp]
2024-04-09 updated PathFollower to do simpler PID following instead. Not done (control flow, knowing when done and turning left (at least))
2024-04-10 added awareness for updated values in sensors, and now waits for all sensors to update before performing pose estimation
2024-04-11 fixed averaging problems with ToF (and IMU) and implemented wanted lag
    [Imu.cpp, Sensors.cpp]
2024-04-11 fixed misc. and ToF wall presence thresholds
    [fusion.cpp, main.cpp]
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2024-04-11 fixed IMU gimbal lock leading to weird angles
    [Imu.cpp]
2024-04-11 fixed wrapping issue in updatePoseComm
    [Imu.cpp]
2024-04-12 fixed weird values due to incomplete switch to probabilithy model
2024-04-12 fixed ghostMove issue with targetFrame in PoseEstimator
    [main.cpp]
2024-04-12 updated robot measurement constants with CAD to be more accurate
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2024-04-13 fixed robot speed calculation
    [main.cpp]
2024-04-13 started PID tuning and made small improvements. Currently broken testing state
    [KinematicDriver.cpp, main.cpp]
2024-04-13 changed teensy motorController to use feedforward (I think)
2024-04-13 fixed motor PID loop
    [MotorController.cpp, Robot.cpp, main.cpp]
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2024-04-13 fixed speed calculation average bug
    [KinematicDriver.cpp]
2024-04-14 tuned some (not all) PID constants and fixed some things for driving
    [KinematicDriver.cpp]
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2024-04-14 fixed tof abs trans y bug which accepted too large values and also bug with values of 0
    [Imu.cpp, fusion.cpp, main.cpp]
2024-04-14 fixed some PathFollower bug when turning and misc. stuff
    [main.cpp]
2024-04-14 made raspberrypi compatible, made code to exctract victim to use for training
2024-04-15 Close to final code -> Read caption
    Close to final code for Linköping IF it is possible for the camera to take a not-shaky-photo when it passes each victim.
    Else
    1. You could try to allow more shaky images for the square detection, but then the risk is that the code becomes more unreliable
    2. Base the detection on thresholds and white scale, i.e. adjust uploaded ColorDetection code to be used as final code or use the code from previous year.
    Status of the code in this commit:
    - Can't detect shaky images
    - Can't detect yellow with too dark lightning condition - TEST how severe this in real-scenario!
    - Risk for wrong detection of yellow if the camera sees big yellow obstacles (w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
2024-04-15 fixed IMU reset issue
    [Imu.cpp]
2024-04-16 improved IMU issue?
2024-04-16 added wheel odometry and improved PID, but no IMU correction yet
    [MotorController.cpp, MotorControllers.cpp, Robot.cpp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]
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2024-04-16 improved IMU issue (frozen values) and misc. other PoseEstimation improvements
    [fusion.cpp]
2024-04-16 added non-working LED code (works with command line tools though, but why not here?)
2024-04-17 (Final) ColoredVictimCode for Linköping
    Implement DetectColor in the main vision code to use the class in the script ColorDetection
    Implement DetectColoredSquare in the main vision code to use the class in the script ColoredSquareDetection
    Code status:
    - Crop image implemented in both scripts but commented out, if needed to only see the wall we can adjust this
    Possible game plan:
    - We should be able to switch between these two scripts, so both needs to be tested.
    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
2024-04-17 Fixed wiringpi setup in LedControl
    [LedControl.cpp]
2024-04-17 added tileDrivePropertyCommunicator to localNav and fixed compilation issue with wiringPi
2024-04-17 updated PID coefficients in files from pid.txt file
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2024-04-17 reverted buggy pose flush behaviour
    [main.cpp]
2024-04-17 added first version of port of colour sensor driver
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2024-04-18 fixed PoseEstimator incremental calc and obstacle detection stopping
    [fusion.cpp, main.cpp]
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2024-04-18 added debugging info and maybe fixed flush
    [main.cpp]
2024-04-18 restructured PoseCommunicator and MotorControllerCommunicator into their own files
2024-04-18 refactored PoseComm to make it thread safe (no changes in the rest of codebase done yet)
2024-04-18 Fixed camera indexes
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2024-04-18 implemented more of new PoseCommunicator and fixed mutex deadlock bug
    [main.cpp]
2024-04-19 added more colour sensor stuff, but I cannot look straight as I type this, so I must go to bed now
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2024-04-19 finished (?) colour detection (no calibration) and added testing to PoseEstimator
2024-04-19 Re-fixed fix where code is fixed by fix, lidar fix and ldlidar is at fault
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2024-04-19 got current Tile colour working for black, blue and white (reflective is giving issues)
    [ColourCalibrator.cpp, fusion.cpp, main.cpp]
2024-04-19 fixed colour threshold storing and another threshold determination bug
    [ColourCalibrator.cpp]
2024-04-19 did fixes to driving backwards
    [main.cpp]
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2024-04-20 Fixed victim handling by doing a switcharoo
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
